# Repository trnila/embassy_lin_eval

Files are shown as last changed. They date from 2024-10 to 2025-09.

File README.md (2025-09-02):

# LIN evaluation board for embassy
LIN eval board utilizing the Rust Embassy framework, featuring:
- 4x LEDs
- 1x RGB LED
- 1x Photoresistor for light sensing
- 1x One-Wire DS18B20 temperature sensor
- 3x jumpers to set board ID (0-7)

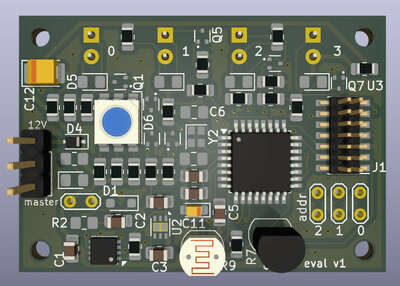
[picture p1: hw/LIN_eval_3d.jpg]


## Build and run

Connect debugger and run:

```shell-session
$ cargo run
```

To initiate LIN communication, connect the PEAK PLIN-USB interface and run the following command:
```shell-session
$ uv run ./commander.py
```

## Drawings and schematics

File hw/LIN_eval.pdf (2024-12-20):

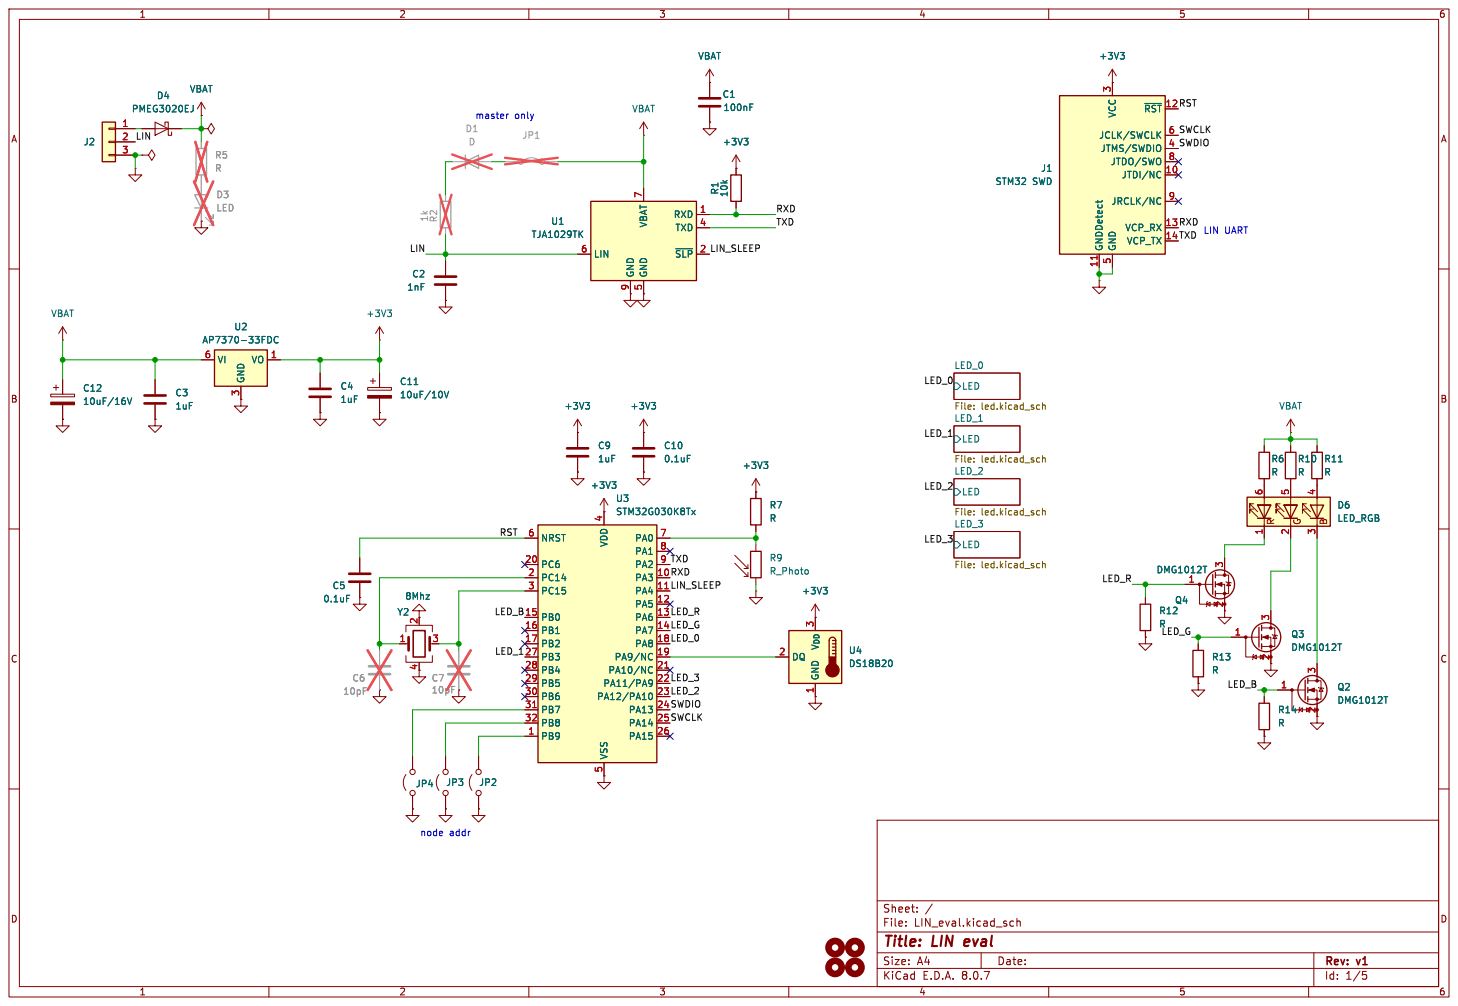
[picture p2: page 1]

5 NRST 6 PA0 7 PA1 8 PA2 9 U3STM32G030K8Tx +3V3 R1 10k RXD 1 ~{SLP}2 TXD 4 GND

Id: 1/5 Title: LIN eval File: LIN_eval.kicad_sch Sheet: /

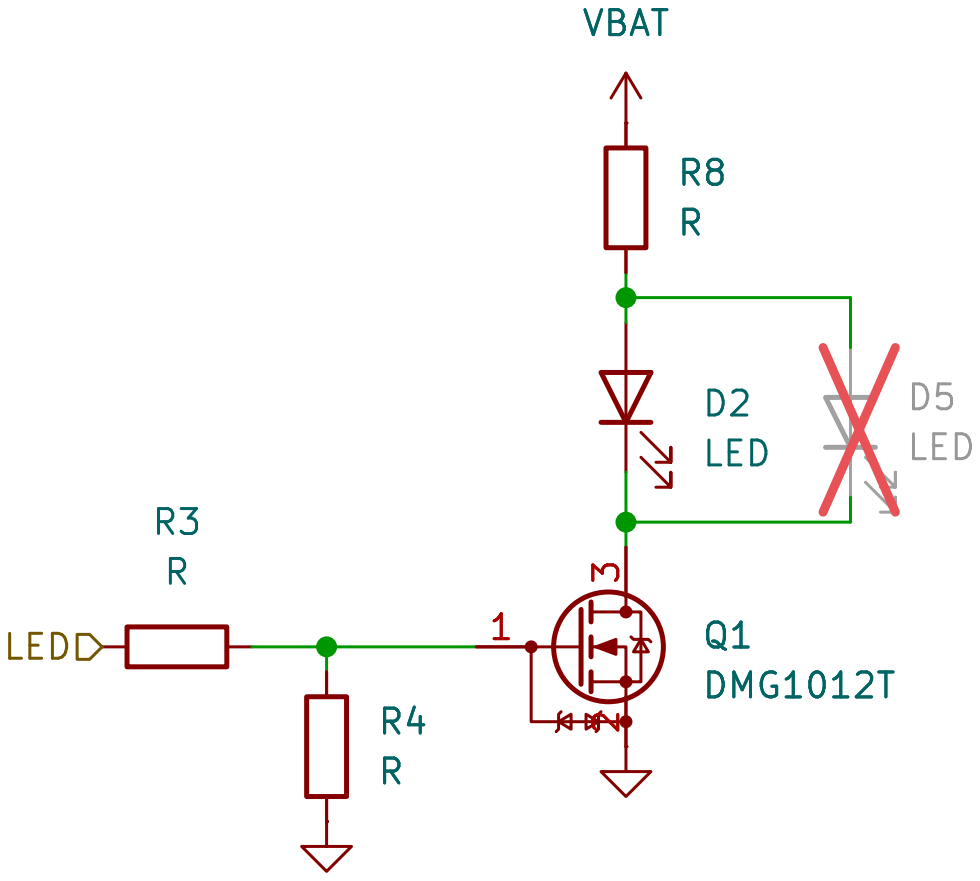
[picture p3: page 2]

Id: 2/5 Title: LIN eval File: led.kicad_sch Sheet: /LED_0/

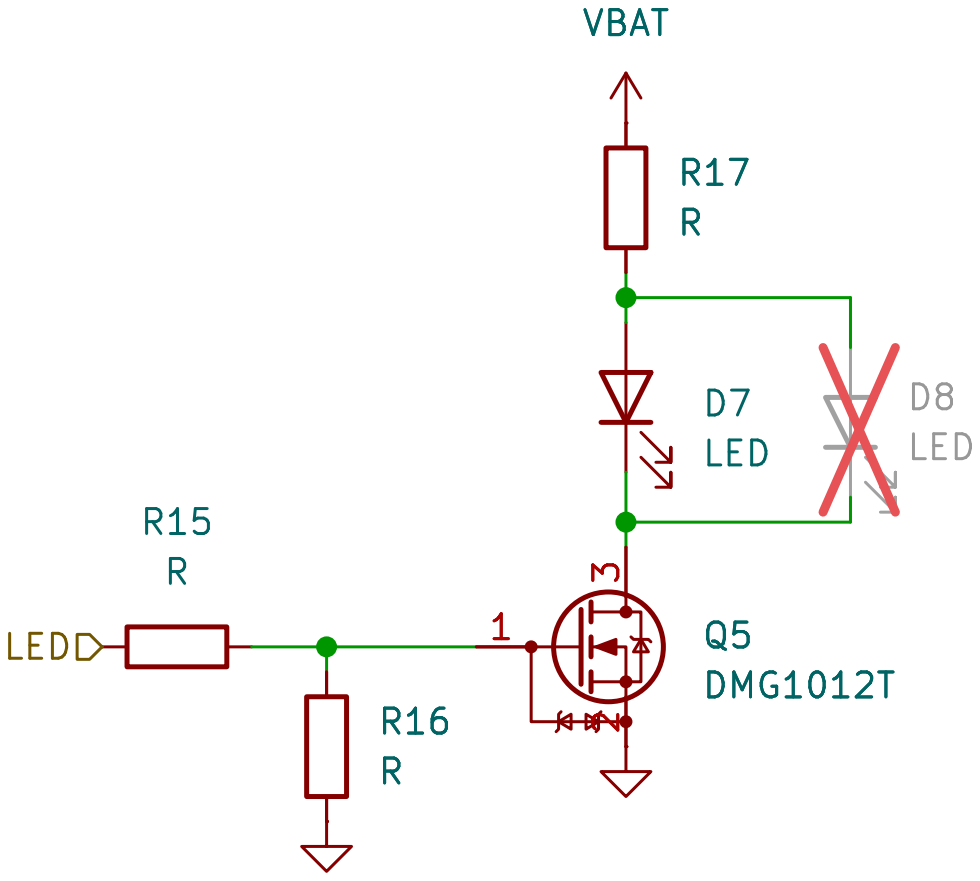
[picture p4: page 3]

Id: 3/5 Title: LIN eval File: led.kicad_sch Sheet: /LED_1/

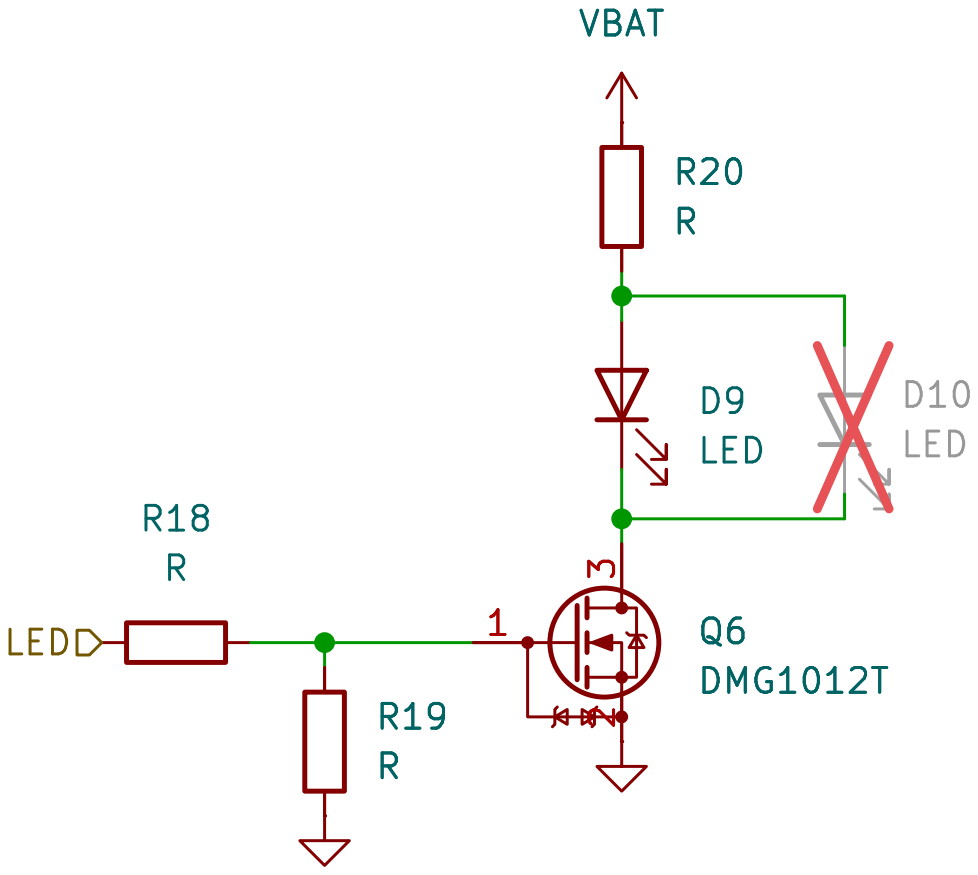
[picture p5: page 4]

Id: 4/5 Title: LIN eval File: led.kicad_sch Sheet: /LED_2/

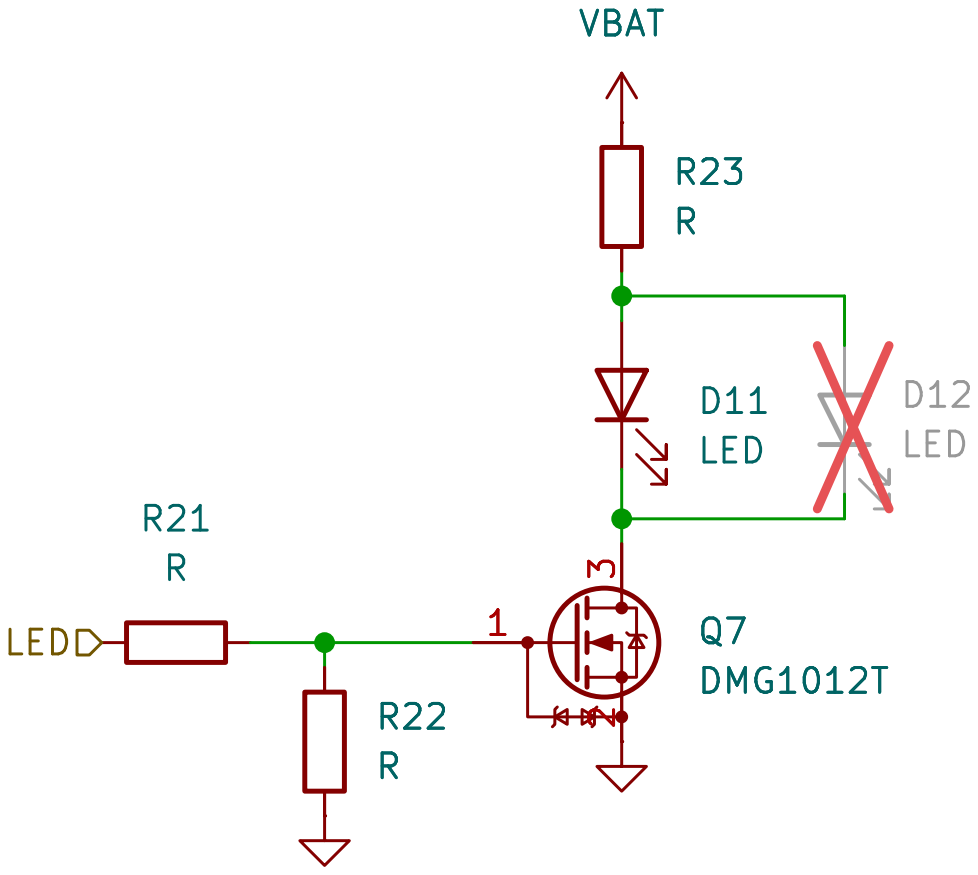
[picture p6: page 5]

Id: 5/5 Title: LIN eval File: led.kicad_sch Sheet: /LED_3/

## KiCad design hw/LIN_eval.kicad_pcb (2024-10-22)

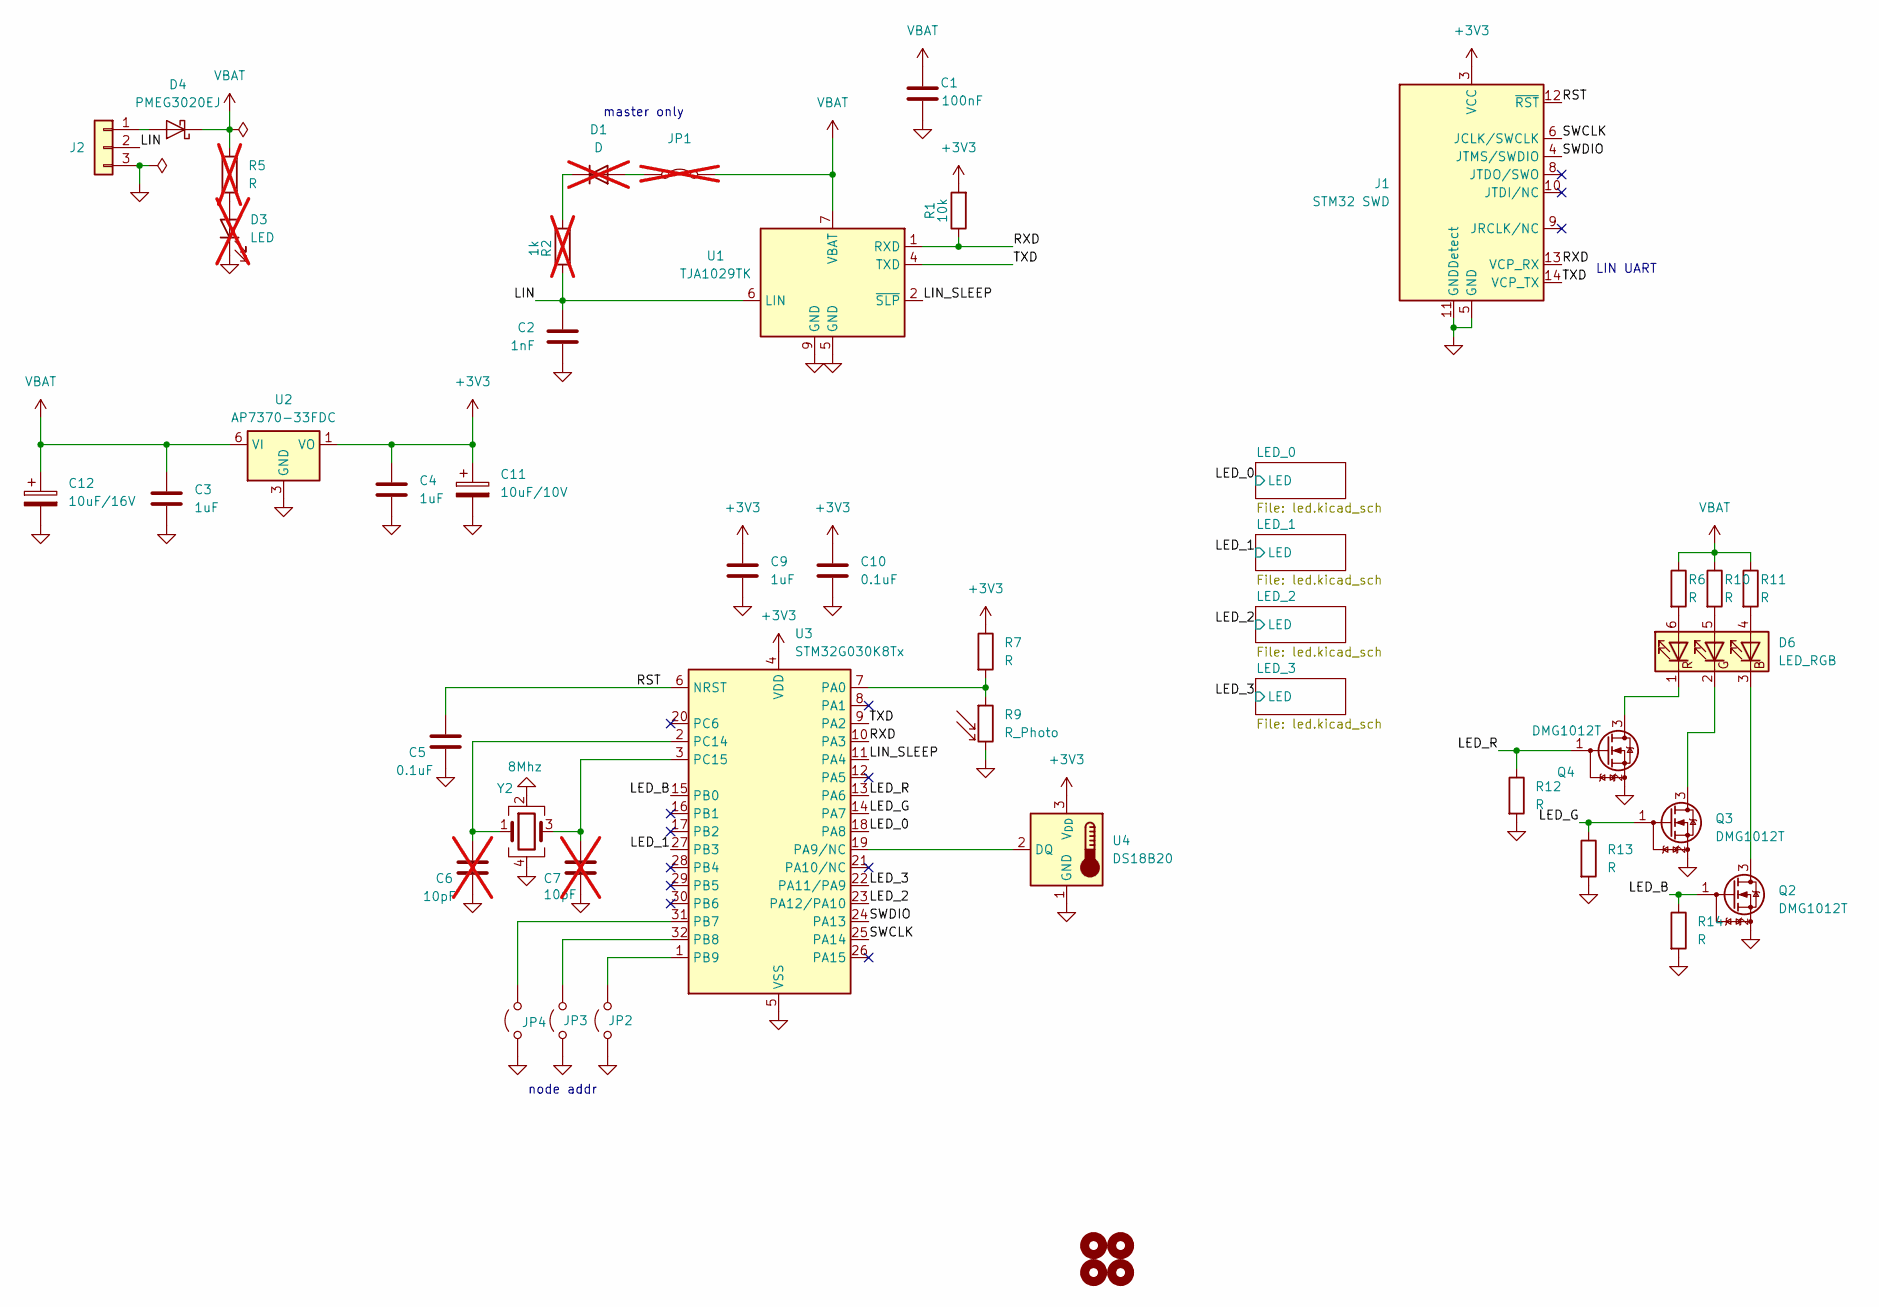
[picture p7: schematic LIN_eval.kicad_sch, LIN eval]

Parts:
C1: 100nF; C_0805_2012Metric_Pad1.18x1.45mm_HandSolder
C2: 1nF; C_0805_2012Metric_Pad1.18x1.45mm_HandSolder
C3, C4, C9: 1uF; C_0805_2012Metric_Pad1.18x1.45mm_HandSolder
C5, C10: 0.1uF; C_0805_2012Metric_Pad1.18x1.45mm_HandSolder
C6, C7: 10pF; C_0805_2012Metric_Pad1.18x1.45mm_HandSolder; not fitted
C11: 10uF/10V; CP_EIA-2012-12_Kemet-R_Pad1.30x1.05mm_HandSolder
C12: 10uF/16V; CP_EIA-3528-15_AVX-H_Pad1.50x2.35mm_HandSolder
D1: D; D_SOD-323_HandSoldering; not fitted
D3: LED; LED_0805_2012Metric_Pad1.15x1.40mm_HandSolder; not fitted
D4: PMEG3020EJ; D_SOD-323F
D6: LED_RGB; LED_RGB_5050-6
H1, H2, H3, H4: MountingHole; MountingHole_2.2mm_M2
J1: STM32 SWD; PinHeader_2x07_P1.27mm_Vertical_SMD
J2: Conn_01x03; PinHeader_1x03_P2.54mm_Vertical
JP1: Jumper_2_Bridged; TestPoint_2Pads_Pitch2.54mm_Drill0.8mm; not fitted
JP2, JP3, JP4: Jumper_2_Open; TestPoint_2Pads_Pitch2.54mm_Drill0.8mm
Q2, Q3, Q4: DMG1012T; SOT-523
R1: 10k; R_0805_2012Metric_Pad1.20x1.40mm_HandSolder
R2: 1k; R_0805_2012Metric_Pad1.20x1.40mm_HandSolder; not fitted
R5: R; R_0805_2012Metric_Pad1.20x1.40mm_HandSolder; not fitted
R6, R7, R10, R11, R12, R13, R14: R; R_0805_2012Metric_Pad1.20x1.40mm_HandSolder
R9: R_Photo; R_LDR_5.0x4.1mm_P3mm_Vertical
U1: TJA1029TK; DFN-8-1EP_3x3mm_P0.65mm_EP1.55x2.4mm
U2: AP7370-33FDC; DFN-6-1EP_2x2mm_P0.65mm_EP1.01x1.7mm
U3: STM32G030K8Tx; LQFP-32_7x7mm_P0.8mm
U4: DS18B20; TO-92_Inline
Y2: 8Mhz; Crystal_SMD_SeikoEpson_FA128-4Pin_2.0x1.6mm

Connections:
+3V3: C4.1, C9.1, C10.1, C11.1, J1.3 (VCC), R1.2, R7.1, U2.1 (VO), U3.4 (VDD), U4.3 (V_{DD})
/LED_0: U3.18 (PA8); also elsewhere on the board
/LED_1: U3.27 (PB3); also elsewhere on the board
/LED_2: U3.23 (PA12/PA10); also elsewhere on the board
/LED_3: U3.22 (PA11/PA9); also elsewhere on the board
/LED_B: Q2.1 (G), R14.1, U3.15 (PB0)
/LED_G: Q3.1 (G), R13.1, U3.14 (PA7)
/LED_R: Q4.1 (G), R12.1, U3.13 (PA6)
/LIN: C2.1, J2.2, R2.2, U1.6 (LIN)
/LIN_SLEEP: U1.2 (~SLP), U3.11 (PA4)
/RST: C5.1, J1.12 (~RST), U3.6 (NRST)
/RXD: J1.13 (VCP_RX), R1.1, U1.1 (RXD), U3.10 (PA3)
/SWCLK: J1.6 (JCLK/SWCLK), U3.25 (PA14)
/SWDIO: J1.4 (JTMS/SWDIO), U3.24 (PA13)
/TXD: J1.14 (VCP_TX), U1.4 (TXD), U3.9 (PA2)
GND: C1.2, C2.2, C3.2, C4.2, C5.2, C6.2, C7.2, C9.2, C10.2, C11.2, C12.2, D3.1 (K), J1.5 (GND), J1.7 (GND), J1.11 (GNDDetect), J2.3, JP2.1 (A), JP3.1 (A), JP4.1 (A), Q2.2 (S), Q3.2 (S), Q4.2 (S), R9.2, R12.2, R13.2, R14.2, U1.5 (GND), U1.9 (GND), U2.3 (GND), U2.7 (GND), U3.5 (VSS), U4.1 (GND), Y2.2, Y2.4; also elsewhere on the board
unnamed: D1.2 (A), JP1.2 (B)
unnamed: D1.1 (K), R2.1
unnamed: D3.2 (A), R5.2
unnamed: D4.2 (A), J2.1
unnamed: D6.4 (BA), R11.2
unnamed: D6.3 (BK), Q2.3 (D)
unnamed: D6.5 (GA), R10.2
unnamed: D6.2 (GK), Q3.3 (D)
unnamed: D6.6 (RA), R6.2
unnamed: D6.1 (RK), Q4.3 (D)
unnamed: JP2.2 (B), U3.1 (PB9)
unnamed: JP3.2 (B), U3.32 (PB8)
unnamed: JP4.2 (B), U3.31 (PB7)
unnamed: R7.2, R9.1, U3.7 (PA0)
unnamed: U3.19 (PA9/NC), U4.2 (DQ)
unnamed: C6.1, U3.2 (PC14), Y2.1
unnamed: C7.1, U3.3 (PC15), Y2.3
VBAT: C1.1, C3.1, C12.1, D4.1 (K), JP1.1 (A), R5.1, R6.1, R10.1, R11.1, U1.7 (VBAT), U2.6 (VI); also elsewhere on the board

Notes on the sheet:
master only
node addr
LIN UART

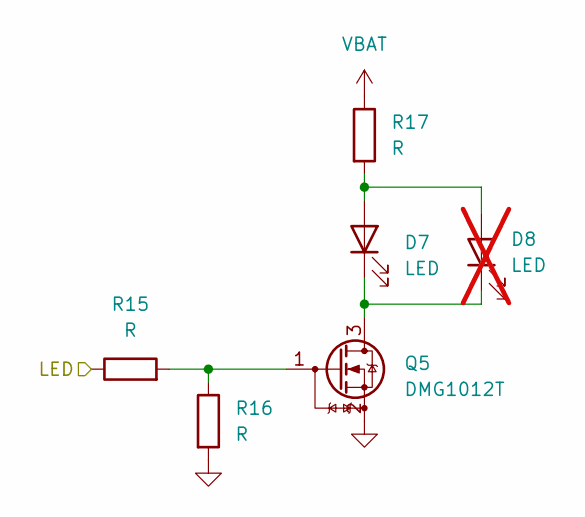
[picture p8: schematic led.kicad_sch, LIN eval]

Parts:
D7: LED; LED_D5.0mm
D8: LED; LED_0805_2012Metric_Pad1.15x1.40mm_HandSolder; not fitted
Q5: DMG1012T; SOT-523
R15, R16, R17: R; R_0805_2012Metric_Pad1.20x1.40mm_HandSolder

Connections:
/LED_1: R15.1; also elsewhere on the board
GND: Q5.2 (S), R16.2; also elsewhere on the board
unnamed: D7.2 (A), D8.2 (A), R17.2
unnamed: D7.1 (K), D8.1 (K), Q5.3 (D)
unnamed: Q5.1 (G), R15.2, R16.1
VBAT: R17.1; also elsewhere on the board

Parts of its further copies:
D2, D9, D11: LED; LED_D5.0mm
D5, D10, D12: LED; LED_0805_2012Metric_Pad1.15x1.40mm_HandSolder; not fitted
Q1, Q6, Q7: DMG1012T; SOT-523
R3, R4, R8, R18, R19, R20, R21, R22, R23: R; R_0805_2012Metric_Pad1.20x1.40mm_HandSolder

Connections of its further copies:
/LED_0: R3.1; also elsewhere on the board
/LED_2: R18.1; also elsewhere on the board
/LED_3: R21.1; also elsewhere on the board
GND: Q1.2 (S), Q6.2 (S), Q7.2 (S), R4.2, R19.2, R22.2; also elsewhere on the board
unnamed: D2.2 (A), D5.2 (A), R8.2
unnamed: D2.1 (K), D5.1 (K), Q1.3 (D)
unnamed: D9.2 (A), D10.2 (A), R20.2
unnamed: D9.1 (K), D10.1 (K), Q6.3 (D)
unnamed: D11.2 (A), D12.2 (A), R23.2
unnamed: D11.1 (K), D12.1 (K), Q7.3 (D)
unnamed: Q1.1 (G), R3.2, R4.1
unnamed: Q6.1 (G), R18.2, R19.1
unnamed: Q7.1 (G), R21.2, R22.1
VBAT: R8.1, R20.1, R23.1; also elsewhere on the board

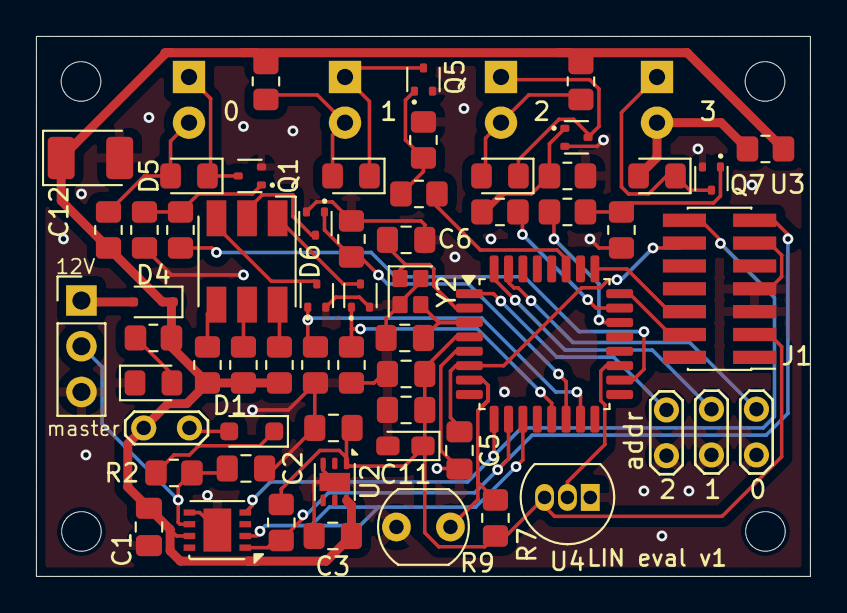
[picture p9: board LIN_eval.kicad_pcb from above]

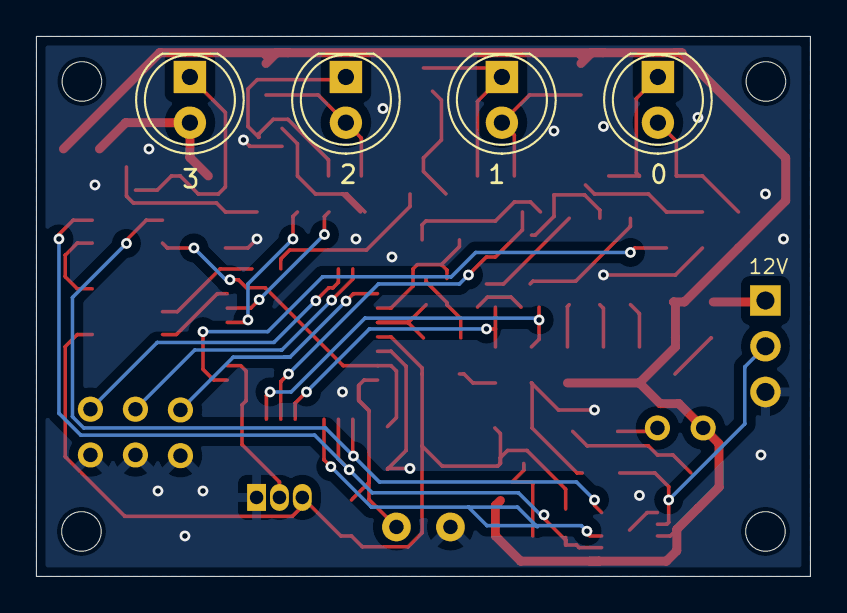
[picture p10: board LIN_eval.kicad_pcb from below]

Board: 2 copper layers, 43.0 x 30.0 mm, 68 parts (4 on the bottom side), 46 nets.

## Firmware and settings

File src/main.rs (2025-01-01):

#![no_std]
#![no_main]

mod ds18b20;
mod lin_slave_driver;
mod lin_slave_handler;
mod onewire;
mod rgb;
mod signals;

use cortex_m::singleton;
use defmt::{error, info};
use lin_slave_handler::LinHandler;
use onewire::OneWire;
#[cfg(not(feature = "defmt"))]
use panic_halt as _;
use signals::{SIGNAL_LEDS, SIGNAL_PHOTORESISTOR, SIGNAL_RGB, SIGNAL_TEMPERATURE};
#[cfg(feature = "defmt")]
use {defmt_rtt as _, panic_probe as _};

use crate::rgb::RGBLed;
use embassy_executor::Spawner;
use embassy_stm32::{
    adc::AdcChannel,
    gpio::OutputType,
    mode::Async,
    time::khz,
    timer::simple_pwm::{PwmPin, SimplePwm},
    usart::{RingBufferedUartRx, Uart, UartTx},
    wdg::IndependentWatchdog,
};
use embassy_stm32::{adc::AnyAdcChannel, timer::Channel as TimChannel};
use embassy_stm32::{
    adc::{Adc, SampleTime},
    peripherals::*,
};
use embassy_stm32::{
    bind_interrupts,
    gpio::{Input, Level, Output, Pull, Speed},
    usart::{self, BufferedUart},
};
use embassy_time::{Duration, Timer};
use lin_slave_driver::lin_slave_driver;

bind_interrupts!(struct UARTIRqs {
    USART2 => usart::BufferedInterruptHandler<USART2>;
});

bind_interrupts!(struct OneWireUsartIrqs {
    USART1 => usart::InterruptHandler<USART1>;
});

#[embassy_executor::task]
async fn rgb_task(mut led: RGBLed<TIM3>) {
    loop {
        let req = SIGNAL_RGB.wait().await;
        led.set(req.r, req.g, req.b);
    }
}

#[embassy_executor::task]
async fn leds_task(mut leds: [Output<'static>; 4]) {
    loop {
        let req = SIGNAL_LEDS.wait().await;
        for (led, state) in leds.iter_mut().zip(req) {
            led.set_level(match state {
                0 => Level::Low,
                _ => Level::High,
            });
        }
    }
}

#[embassy_executor::task]
async fn lin_slave_task(uart: BufferedUart<'static>, _lin_sleep: Output<'static>, board_id: u8) {
    let handler = LinHandler::new(board_id);
    lin_slave_driver(uart, handler).await;
}

#[embassy_executor::task]
async fn adc_task(
    mut adc: Adc<'static, ADC1>,
    mut dma: DMA1_CH1,
    mut channel: AnyAdcChannel<ADC1>,
) {
    let read_buffer: &mut [u16; 2] = singleton!(ADC_BUF: [u16; 2] = [0; 2]).unwrap();
    let mut vrefint_channel = adc.enable_vrefint().degrade_adc();

    loop {
        adc.read(
            &mut dma,
            [
                (&mut vrefint_channel, SampleTime::CYCLES160_5),
                (&mut channel, SampleTime::CYCLES160_5),
            ]
            .into_iter(),
            read_buffer,
        )
        .await;

        let vrefint = read_buffer[1];
        let measured = read_buffer[0];

        const VREFINT_MV: u32 = 1212; // mV
        let measured_mv: u16 = (u32::from(measured) * VREFINT_MV / u32::from(vrefint)) as u16;

        SIGNAL_PHOTORESISTOR.signal(measured_mv);

        info!("vrefint: {} PA0: {} {}mV", vrefint, measured, measured_mv);
        Timer::after(Duration::from_millis(500)).await;
    }
}

#[embassy_executor::task]
async fn watchdog_task(mut wdg: IndependentWatchdog<'static, IWDG>) {
    loop {
        Timer::after_secs(1).await;
        wdg.pet();
    }
}

fn get_board_id(pins: &[Input]) -> u8 {
    pins.iter()
        .enumerate()
        .map(|(pos, pin)| {
            if pin.is_low() {
                2u8.pow((pins.len() - 1 - pos) as u32)
            } else {
                0
            }
        })
        .sum()
}

#[embassy_executor::main]
async fn main(spawner: Spawner) {
    let p = embassy_stm32::init(Default::default());
    let mut wdg = IndependentWatchdog::new(p.IWDG, 2_000_000);
    wdg.unleash();
    spawner.spawn(watchdog_task(wdg)).unwrap();

    SIGNAL_TEMPERATURE.signal(None);

    let board_id = get_board_id(&[
        Input::new(p.PB9, Pull::Up),
        Input::new(p.PB8, Pull::Up),
        Input::new(p.PB7, Pull::Up),
    ]);
    info!("Board id: {}", board_id);

    let leds = [
        Output::new(p.PA8, Level::Low, Speed::Low),
        Output::new(p.PB3, Level::Low, Speed::Low),
        Output::new(p.PA12, Level::Low, Speed::Low),
        Output::new(p.PA11, Level::Low, Speed::Low),
    ];
    let lin_sleep = Output::new(p.PA4, Level::High, Speed::Low);

    let rgb_blue_ch = PwmPin::new_ch1(p.PA6, OutputType::PushPull);
    let rgb_red_ch = PwmPin::new_ch2(p.PA7, OutputType::PushPull);
    let rgb_green_ch = PwmPin::new_ch3(p.PB0, OutputType::PushPull);

    let pwm = SimplePwm::new(
        p.TIM3,
        Some(rgb_blue_ch),
        Some(rgb_red_ch),
        Some(rgb_green_ch),
        None,
        khz(1),
        Default::default(),
    );
    let pwm_rgb = RGBLed::new(pwm, TimChannel::Ch2, TimChannel::Ch3, TimChannel::Ch1);

    let config = {
        let mut config = usart::Config::default();
        config.baudrate = 19200;
        //config.extended_feature = Some(ExtendedFeature::LIN);
        config
    };

    let tx_buf: &mut [u8; 32] = singleton!(TX_BUF: [u8; 32] = [0; 32]).unwrap();
    let rx_buf: &mut [u8; 32] = singleton!(RX_BUF: [u8; 32] = [0; 32]).unwrap();
    let uart = BufferedUart::new(p.USART2, UARTIRqs, p.PA3, p.PA2, tx_buf, rx_buf, config).unwrap();

    let adc = Adc::new(p.ADC1);
    let dma = p.DMA1_CH1;
    let pa0 = p.PA0.degrade_adc();

    let onewire_usart = Uart::new_half_duplex(
        p.USART1,
        p.PA9,
        OneWireUsartIrqs,
        p.DMA1_CH2,
        p.DMA1_CH3,
        usart::Config::default(),
        // Enable readback so we can read sensor pulling data low while transmission is in progress
        usart::HalfDuplexReadback::Readback,
        usart::HalfDuplexConfig::OpenDrainExternal,
    )
    .unwrap();

    const BUFFER_SIZE: usize = 16;
    let (tx, rx) = onewire_usart.split();
    let rx_buf: &mut [u8; BUFFER_SIZE] =
        singleton!(TX_BUF: [u8; BUFFER_SIZE] = [0; BUFFER_SIZE]).unwrap();
    let rx = rx.into_ring_buffered(rx_buf);
    let onewire = OneWire::new(tx, rx);

    spawner
        .spawn(lin_slave_task(uart, lin_sleep, board_id))
        .unwrap();
    spawner.spawn(rgb_task(pwm_rgb)).unwrap();
    spawner.spawn(leds_task(leds)).unwrap();
    spawner.spawn(adc_task(adc, dma, pa0)).unwrap();
    spawner.spawn(ds18b20_task(onewire)).unwrap();
}

#[embassy_executor::task]
async fn ds18b20_task(onewire: OneWire<UartTx<'static, Async>, RingBufferedUartRx<'static>>) {
    let mut sensor: ds18b20::Ds18b20<UartTx<'_, Async>, RingBufferedUartRx<'_>> =
        ds18b20::Ds18b20::new(onewire);
    loop {
        SIGNAL_TEMPERATURE.signal(match sensor.raw_temperature().await {
            Ok(raw_temperature) => {
                info!("Temperature: {}°C", raw_temperature as f32 / 16.);
                Some(raw_temperature)
            }
            Err(_) => {
                error!("Failed to read temperature");
                None
            }
        });

        Timer::after(Duration::from_secs(1)).await;
    }
}

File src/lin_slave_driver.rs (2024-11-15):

use defmt::info;
use embassy_stm32::usart::BufferedUart;
use embedded_io_async::Read;
use embedded_io_async::Write;
use lin_bus::Frame;
use lin_bus::PID;

pub trait LinSlaveHandler {
    /// expected size of master frame
    fn master_frame_size(&mut self, frame_id: u8) -> Option<usize>;

    /// process data received from master
    fn process_master_frame(&mut self, frame_id: u8, data: &[u8]);

    /// prepare a data for master request
    fn make_slave_response(&mut self, frame_id: u8) -> Option<&[u8]>;
}

pub async fn lin_slave_driver<T: LinSlaveHandler>(mut uart: BufferedUart<'static>, mut handler: T) {
    loop {
        let mut buf = [0u8; 1];
        uart.read_exact(&mut buf).await.unwrap();
        if buf[0] != 0 {
            continue;
        }

        uart.read_exact(&mut buf).await.unwrap();
        if buf[0] != 0x55 {
            continue;
        }

        uart.read_exact(&mut buf).await.unwrap();
        let pid = PID::new(buf[0]);
        if pid.is_err() {
            info!("bad PID");
            continue;
        }
        let pid = pid.unwrap();
        if let Some(data) = handler.make_slave_response(pid.get_id()) {
            uart.write_all(Frame::from_data(pid, data).get_data_with_checksum())
                .await
                .unwrap();
        } else if let Some(len) = handler.master_frame_size(pid.get_id()) {
            let mut buf = [0u8; 9];

            uart.read_exact(&mut buf[..=len]).await.unwrap();

            let frame = Frame::from_data(pid, &buf[..len]);
            let valid = frame.get_checksum() == buf[len];

            info!("{} {:x} {}", pid.get_id(), buf[..=len], valid);
            if valid {
                handler.process_master_frame(frame.get_pid().get_id(), frame.get_data());
            }
        } else {
            info!("drop unknown");
        }
    }
}

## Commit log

2024-10-22 dont print location
2024-10-22 Toggle all LEDs
2024-10-22 bring up adc
2024-10-22 Use pwm for RGB led
2024-10-22 Snake led animation via LIN
2024-10-22 Measure photoresistor mV and respond to master LIN frames
2024-10-22 Calculate board id from pins
2024-11-14 lin_slave: use frame_id instead of PID in processing functions
2024-11-14 Split LIN to driver and frame handler
2024-11-14 lin_slave_handler: offset LIN frames by board_id * 5
2024-11-15 commander.py: communicate with multiple boards
2024-11-15 using unreleased patch for detecting wrong PIDs in lin-bus-rs
    [lin_slave_driver.rs]
2024-11-15 commander: frame merges signals instead of overwritting whole frame
2024-12-20 hw: added pdf schematics
2025-01-01 Measure temperature with DS18B20 on onewire bus
